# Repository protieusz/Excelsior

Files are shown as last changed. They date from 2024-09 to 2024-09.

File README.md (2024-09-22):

# Excelsior
Excelsior, 34 keys unisplit ortho with staggered pinkies &amp; 25mm trackball, optional RGB strip.

# Description
Excelsior is a heavily modified version of Endzone34 which has been blessed by takashicompany himself for the mod. [Endzone34](https://github.com/takashicompany/endzone34) was originally designed by takashicompany.

A List Of Mods Made To The Original PCB by [takashicompany](https://github.com/takashicompany/endzone34):

-PCB was created from scratch using the outline shape of Endzone34 using EasyEDA.

-A circular hole was created in the middle that can accomodate either a 25mm trackball powered by PMW3360 sensor.

-Base of the trackball holder with lens cut out is integrated into the top case with integrated 5mm switch plate. Top case sits flush with pcb.

-This PCB is capable of hot swap, Kailh.

-Full keyboard case was created to house the PCB.

-MCU area is now hidden and have an extrude of a [Starship logo](https://www.clipartmax.com/middle/m2i8Z5m2d3b1K9m2_star-trek-ship-icon-icon/)

-Excelsior is powered by [RP2040 Zero Raspberry Pi SuperMini Pico](https://www.aliexpress.com/item/1005007292787135.html?spm=a2g0o.order_list.order_list_main.136.6e251802pcq7qH) which you can get from AE and is soldered at the bottom of the pcb flush to the pcb.

-For diodes, I decided to try out the [BAV70](https://www.lcsc.com/product-detail/Switching-Diode_Jiangsu-Changjing-Electronics-Technology-Co-Ltd-BAV70_C68978.html) so that I solder less diodes since this pcb
is not sponsored. I would only need to solder on 17 diodes instead of 34.

-PCB has the option of RGB strip and the power 5v has the proper power level shifter component soldered on. Initially I was gonna do individual 34 RGBs but too much work and I don't use RGBs that often.

-QMK code is borrowed from aki27 bally and modified the matrix to fit my Excelsior. No suppport will be given since I just copy and paste.

-Keycaps I prefer high profile ones, MT3 or SA.

-Use M2 brass hot inserts 3.2mm diameter and 4mm length for the M2 screws to secure the case. I forgot how long is my M2 screws are but they should be greater than 10mm so estimated around 14.6mm. Play around with and buy multiple M2 lenght screws.

# Disclaimer
The trackball user experience might differ depending on the types of 3D printer that you use or if the printers were calibrated properly. It might be a hit and miss. The experience can also be adjust on the QMK side on the CPI settings. No
support will be given since the code was copy pasted from bally by aki27. As for the ball material and sizing plays a big role on the user experience. I personally prefer the BOM ball 25mm compared to the other different materials. Try it out and experiment it. As per usual print and use at your own risk. No support will be given. This design is MIT licensed so that means you can modify and do whatever you want with the design. If you do modify my design, please be kind to give me a shout out. PCB file is converted from EasyEDA so the convertion accuracy might not be good and KiCad DRC will scream but on EasyEDA DRC is fine. As the time of writing, the Excelsior is 100% working with no issues on my end.  Results might differ on your end.  A all in one Fusion file for the case that include the sketches is also included in this GitHub.  Thanks. 

# Full Production Pictures
TBA. Currently Sept 13, 2024, the PCBs are in transit from JLCPCB.
Sept 22, 2024, PCBs have arrived and build was a success!!!






















# Renders
Screenshot 2024-09-13 at 2 24 26 PM
Screenshot 2024-09-13 at 2 24 42 PM





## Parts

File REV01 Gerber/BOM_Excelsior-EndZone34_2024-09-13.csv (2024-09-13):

ID | Name | Designator | Footprint | Quantity | Manufacturer Part | Manufacturer | Supplier | Supplier Part | Price | link
1 | Kailh MX Hotswap | K000,K001,K002,K003,K004,K005,K006,K007,K008,K009,K100,K101,K102,K103,K104,K105,K106,K107,K108,K109,K200,K201,K202,K203,K204,K205,K206,K207,K208,K209,K303,K304,K305,K306 | KAILH MX HOTSWAP | 34 | 4958 | Adafruit Industries LLC | Digi-Key | 1528-4958-ND |  | https://www.digikey.fr/fr/products/detail/adafruit-industries-llc/4958/13997772
2 | NO | 5V,DIN,GND | PIN 1-PIN | 3
3 | SN74LVC1T45QDCKRQ1 | U6 | SC-70-6_L2.0-W1.3-P0.65-LS2.1-BR | 1 | SN74LVC1T45QDCKRQ1 | TI(德州仪器) | LCSC | C139353 | 0.443 | https://lcsc.com/eda_search?q=C139353&%26type=1&ref=editor
4 | RP2040-TINY | U2 | COMM-SMD_23P-P2.54-L23.5-W18.0_RP2040-TINY | 1 | RP2040-Tiny | Waveshare(微雪电子) | LCSC | C7437606 | 5.586 | https://atta.szlcsc.com/upload/public/pdf/source/20230712/B68EE20814230DC1A1AC8A477766A0F3.pdf
5 | PMW3360DM-T2QU | U11 | PMW3360DM-T2QU.PACK | 1 | PMW3360DM-T2QU |  |  |  |  | http://www.pixart.com/upload/PMS0058-PMW3360DM-T2QU-NNDS-R1.30-06042016_20160902201411.pdf
6 | BAV70-C68978 | D000,D002,D004,D006,D008,D100,D102,D104,D106,D108,D200,D202,D204,D206,D208,D303,D305 | SOT-23-3_L3.0-W1.7-P0.95-LS2.9-BR | 17 | BAV70 | CJ(江苏长电/长晶) | LCSC | C68978 | 0.019 | https://item.szlcsc.com/139341.html
7 | 4.7uF | C17,C19,C20 | C0402 | 3 | CL05A475MP5NRNC | SAMSUNG(三星) | LCSC | C23733 | 0.005 | https://lcsc.com/eda_search?q=C23733&%26type=1&ref=editor
8 | 100nF | C18 | C0402 | 1 | CL05B104KB54PNC | SAMSUNG(三星) | LCSC | C307331 | 0.005 | https://lcsc.com/eda_search?q=C307331&%26type=1&ref=editor
9 | 10kΩ | R10,R12,R13 | R0402 | 3 | 0402WGF1002TCE | UNI-ROYAL(厚声) | LCSC | C25744 | 0.001 | https://lcsc.com/eda_search?q=C25744&%26type=1&ref=editor
10 | 39Ω | R11 | R0402 | 1 | 0402WGJ0390TCE | UNI-ROYAL(厚声) | LCSC | C25164 |  | https://lcsc.com/eda_search?q=C25164&%26type=1&ref=editor
11 | 15kΩ | R14 | R0402 | 1 | 0402WGF1502TCE | UNI-ROYAL(厚声) | LCSC | C25756 | 0.001 | https://lcsc.com/eda_search?q=C25756&%26type=1&ref=editor
12 | AP2127K-ADJTRG1 | U10 | SOT-23-5_L3.0-W1.7-P0.95-LS2.8-BR | 1 | AP2127K-ADJTRG1 | DIODES(美台) | LCSC | C96343 | 0.074 | https://lcsc.com/eda_search?q=C96343&%26type=1&ref=editor

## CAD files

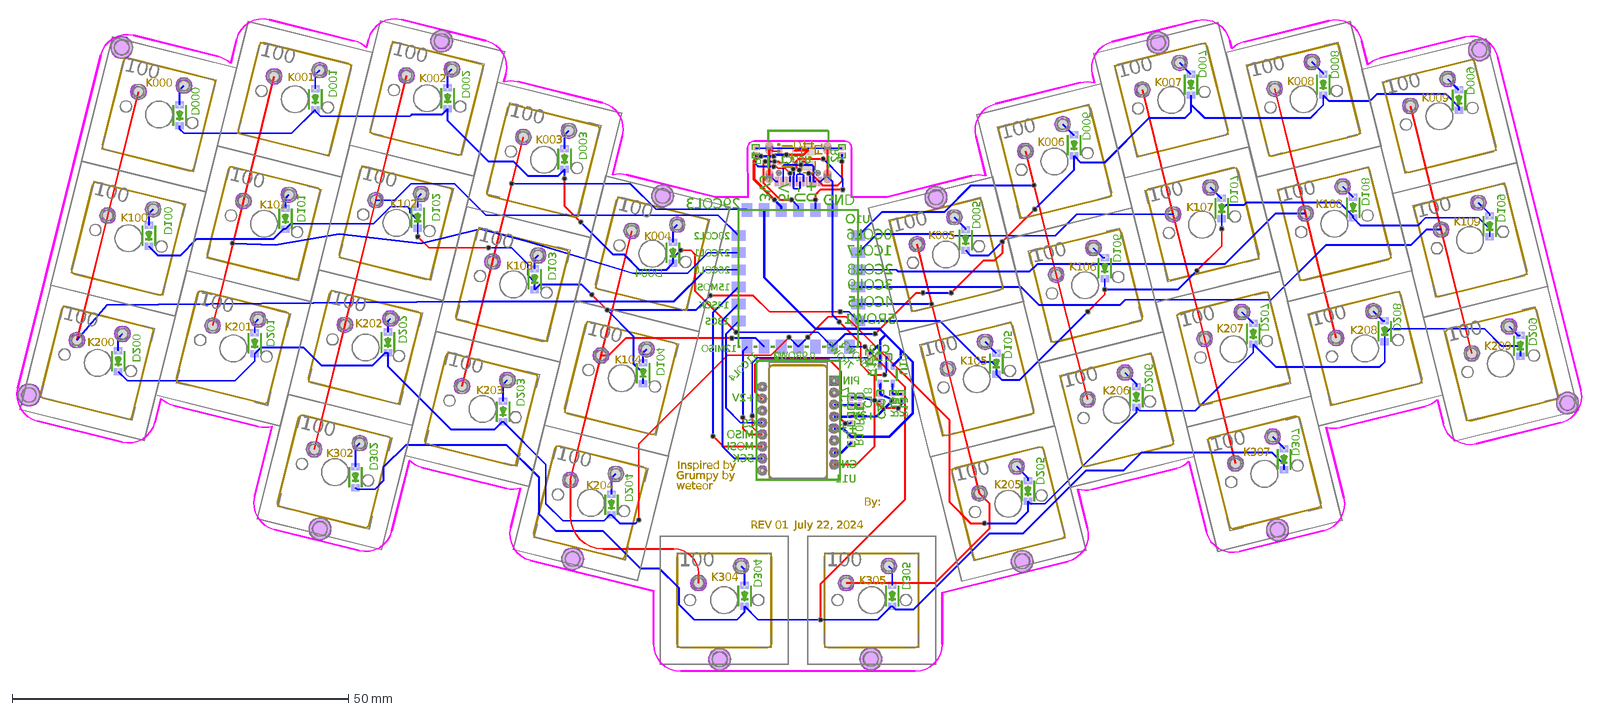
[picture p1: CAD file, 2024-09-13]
PCB_Angel_2024-09-05.dxf
By:
REV 01
July 22, 2024
Inspired by
Grumpy by
weteor
PIN 1
+2V
+3V3
GND
SCK
MOSI
MISO
CS
D000
D001
D002
D003
D004
D005
D006
D007
D008
D009
D100
D101
D102
D103
D104
D105
D106
D107
D108
D109
D200
D201
D202
D203
D204
D205
D206
D207
D208
D209
D302
D304
D305
D307
C17
C18
C19
C20
R1
R2
R10
R11
R12
R13
R14
U1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

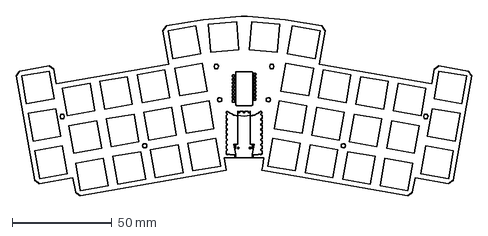
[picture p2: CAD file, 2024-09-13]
pcbtemplate/Excelsior PCB Template.dxf
227.9 x 89.8 mm

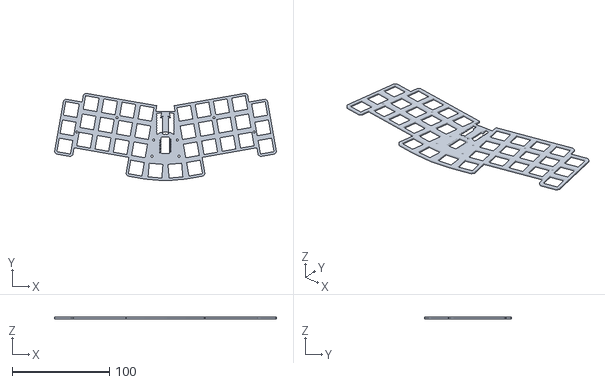
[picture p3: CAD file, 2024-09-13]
STLs/Excelsior PCB.stl
227.9 x 89.8 x 1.60

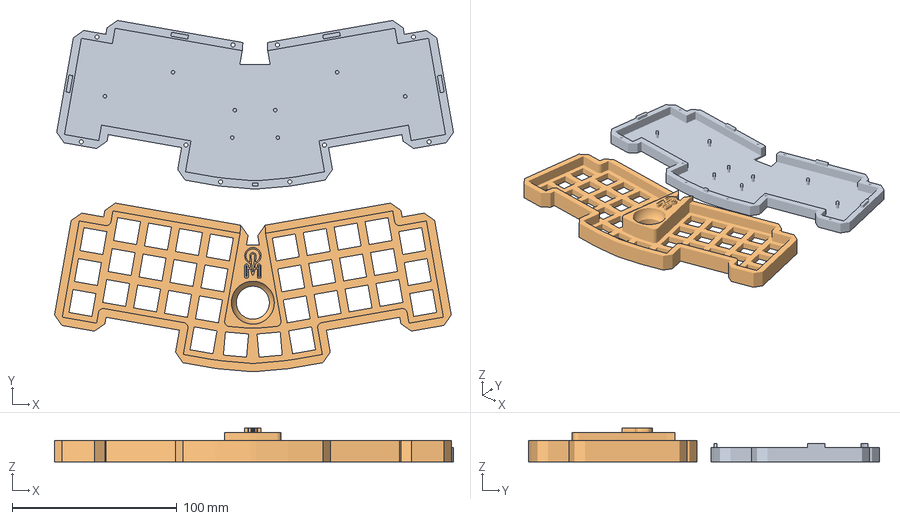
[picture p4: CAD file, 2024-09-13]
STLs/RPL/UMS7_ExcelsiorAll.3mf
241.9 x 212.9 x 20.4 mm
Excelsior Bottom.stl
Excelsior Top.stl

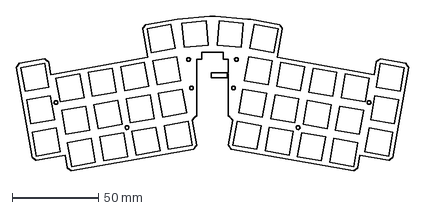
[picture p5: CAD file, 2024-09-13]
Template/Excelsior EndZone34 template.dxf
227.9 x 89.8 mm

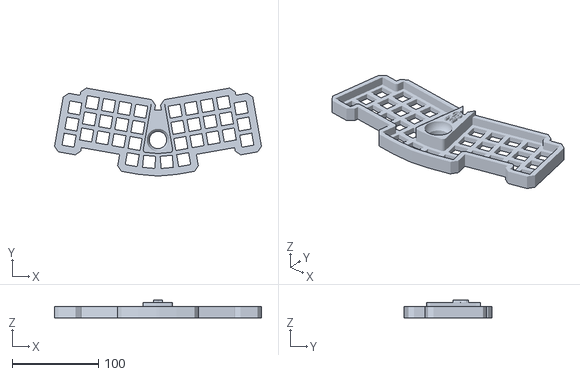
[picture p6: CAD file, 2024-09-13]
STLs/Excelsior Top.stl
240.6 x 102.1 x 20.4

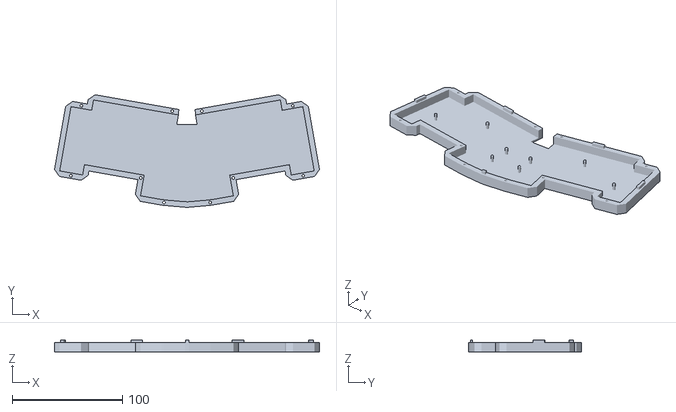
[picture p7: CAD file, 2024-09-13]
STLs/Excelsior Bottom.stl
240.6 x 102.1 x 11.1

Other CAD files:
pcbtemplate/Excelsior PCB.step

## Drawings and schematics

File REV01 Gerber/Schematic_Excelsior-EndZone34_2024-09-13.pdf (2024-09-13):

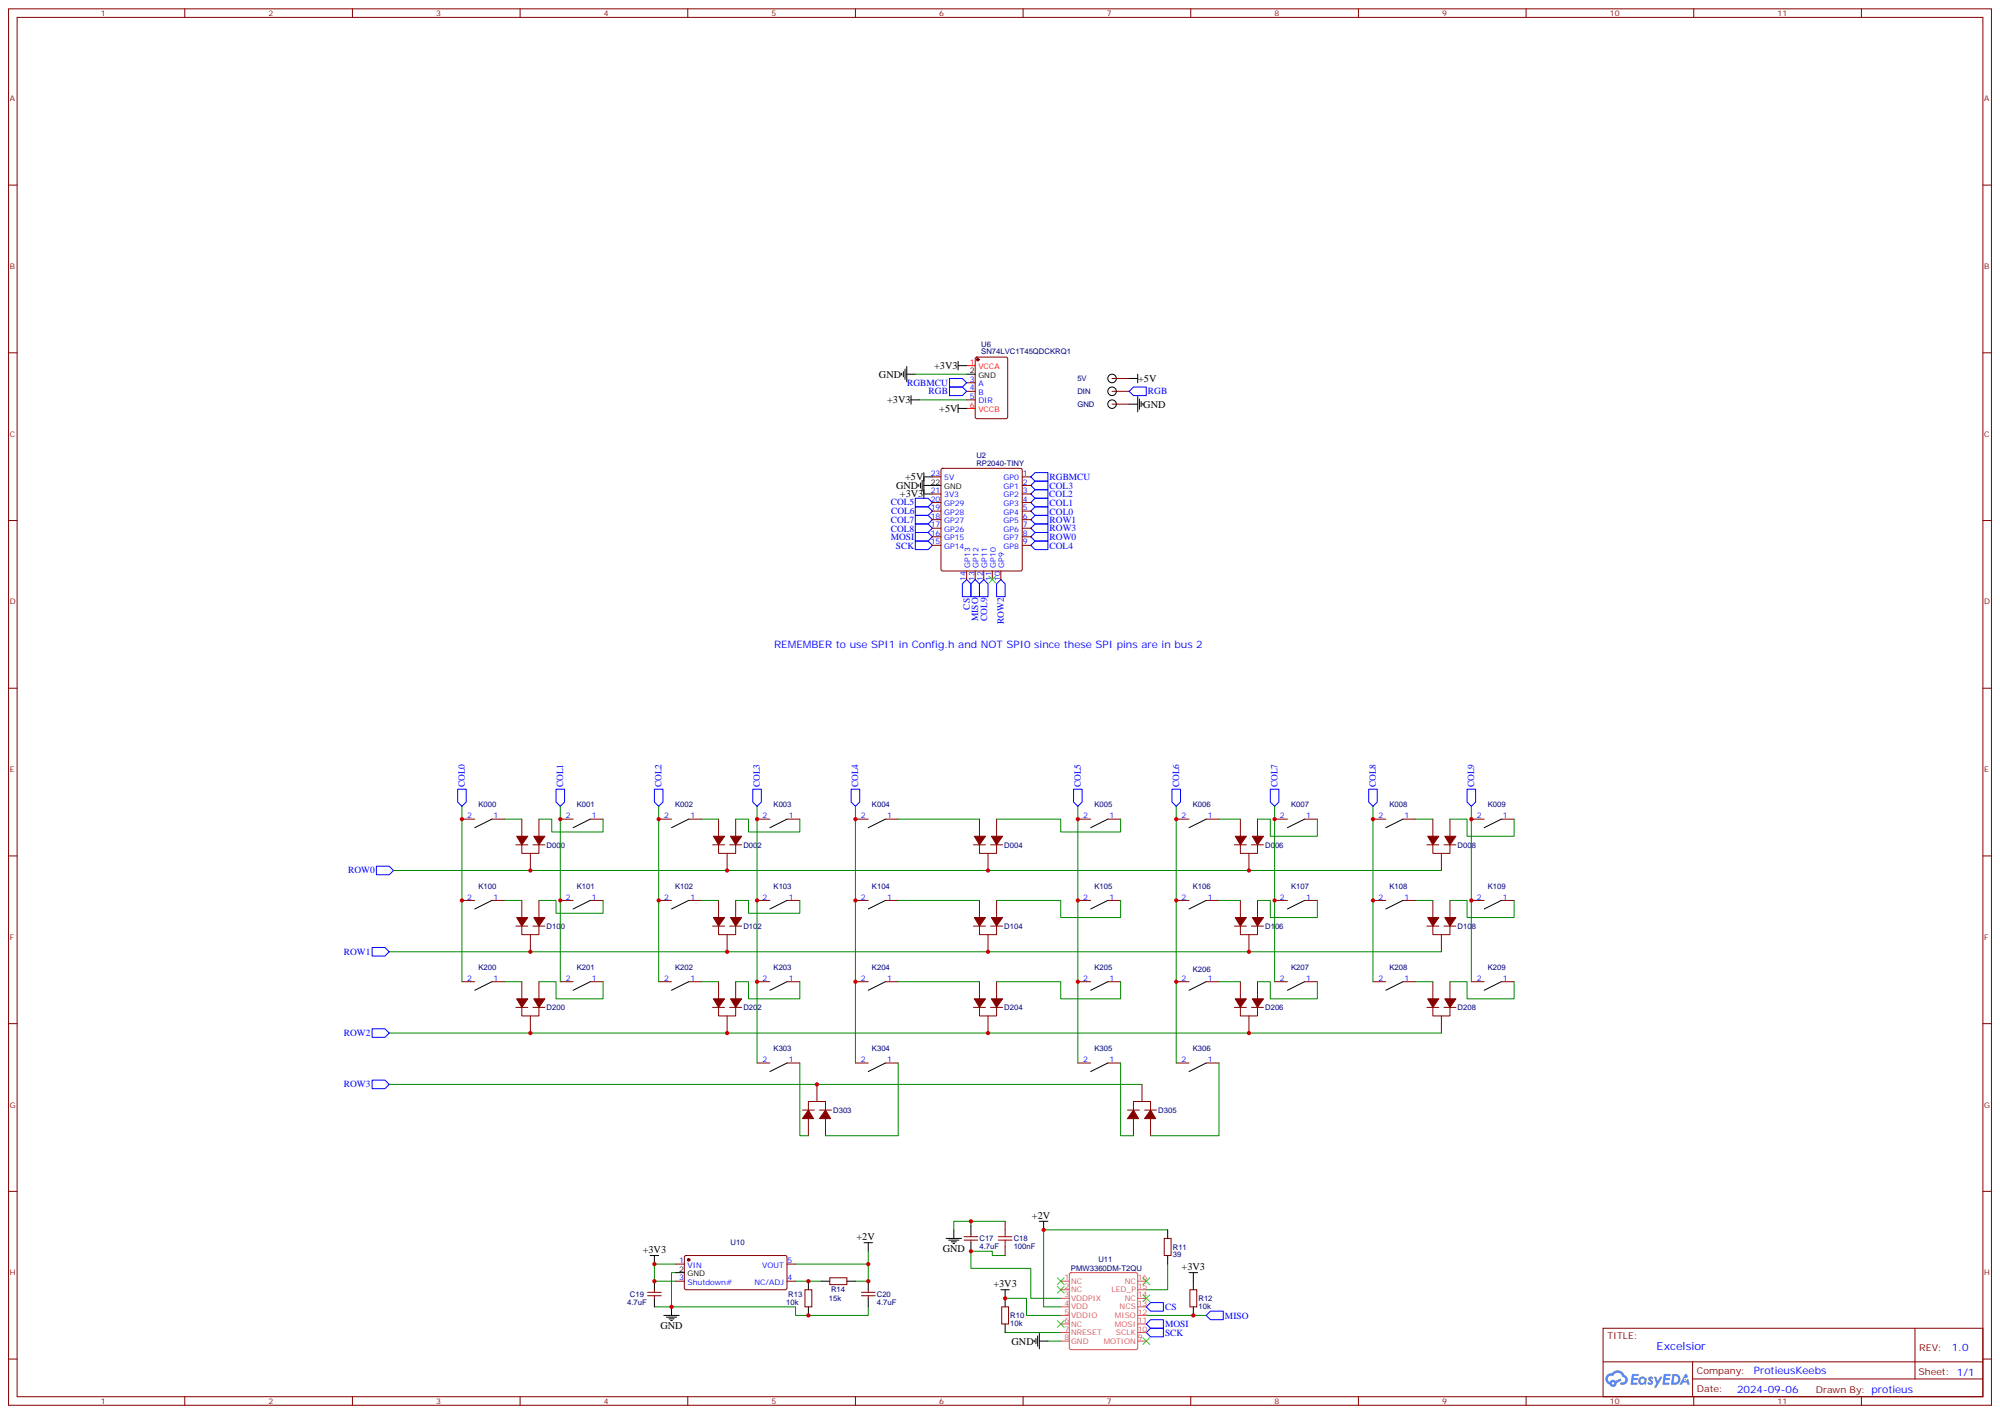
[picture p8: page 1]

REMEMBER to use SPI1 in Config.h and NOT SPI0 since these SPI pins are in bus 2

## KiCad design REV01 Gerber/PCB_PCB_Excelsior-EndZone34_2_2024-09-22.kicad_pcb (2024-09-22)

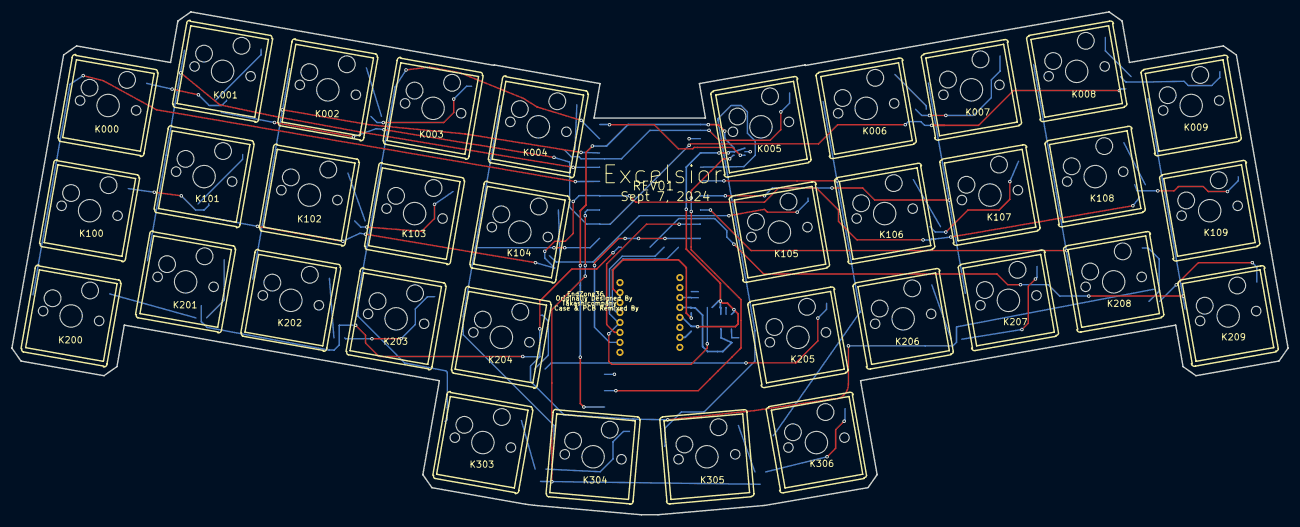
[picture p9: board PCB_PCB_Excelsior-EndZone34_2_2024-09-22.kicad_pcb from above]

Board: 2 copper layers, 227.9 x 89.8 mm, 67 parts (0 on the bottom side), 62 nets.

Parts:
5V: NO; PIN 1-PIN
C17, C19, C20: 4.7uF; C0402
C18: 100nF; C0402
D000, D002, D004, D006, D008, D100, D102, D104, D106, D108, D200, D202, D204, D206, D208, D303, D305: BAV70-C68978; SOT-23-3_L3.0-W1.7-P0.95-LS2.9-BR
DIN: NO; PIN 1-PIN
GND: NO; PIN 1-PIN
K000, K001, K002, K003, K004, K005, K006, K007, K008, K009, K100, K101, K102, K103, K104, K105, K106, K107, K108, K109, K200, K201, K202, K203, K204, K205, K206, K207, K208, K209, K303, K304, K305, K306: Kailh MX Hotswap; KAILH MX HOTSWAP
R10, R12, R13: 10kΩ; R0402
R11: 39Ω; R0402
R14: 15kΩ; R0402
U2: RP2040-TINY; COMM-SMD_23P-P2.54-L23.5-W18.0_RP2040-TINY
U6: SN74LVC1T45QDCKRQ1; SC-70-6_L2.0-W1.3-P0.65-LS2.1-BR
U10: AP2127K-ADJTRG1; SOT-23-5_L3.0-W1.7-P0.95-LS2.8-BR
U11: PMW3360DM-T2QU; PMW3360DM-T2QU.PACK

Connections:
+2V: C20.2, R11.2, R14.2, U10.5, U11.4
+3V3: C19.2, R10.2, R12.2, U2.21, U6.1, U6.5, U10.1, U10.3, U11.5
+5V: 5V.1, U2.23, U6.6
C18_1: C17.1, C18.1, U11.3
COL0: K000.2, K100.2, K200.2, U2.5
COL1: K001.2, K101.2, K201.2, U2.4
COL2: K002.2, K102.2, K202.2, U2.3
COL3: K003.2, K103.2, K203.2, K303.2, U2.2
COL4: K004.2, K104.2, K204.2, K304.2, U2.9
COL5: K005.2, K105.2, K205.2, K305.2, U2.20
COL6: K006.2, K106.2, K206.2, K306.2, U2.19
COL7: K007.2, K107.2, K207.2, U2.18
COL8: K008.2, K108.2, K208.2, U2.17
COL9: K009.2, K109.2, K209.2, U2.12
CS: U2.14, U11.13
GND: C17.2, C18.2, C19.1, C20.1, GND.1, R13.1, U2.22, U6.2, U10.2, U11.8
K000_1: D000.2, K000.1
K001_1: D000.1, K001.1
K002_1: D002.2, K002.1
K003_1: D002.1, K003.1
K004_1: D004.2, K004.1
K005_1: D004.1, K005.1
K006_1: D006.2, K006.1
K007_1: D006.1, K007.1
K008_1: D008.2, K008.1
K009_1: D008.1, K009.1
K100_1: D100.2, K100.1
K101_1: D100.1, K101.1
K102_1: D102.2, K102.1
K103_1: D102.1, K103.1
K104_1: D104.2, K104.1
K105_1: D104.1, K105.1
K106_1: D106.2, K106.1
K107_1: D106.1, K107.1
K108_1: D108.2, K108.1
K109_1: D108.1, K109.1
K200_1: D200.2, K200.1
K201_1: D200.1, K201.1
K202_1: D202.2, K202.1
K203_1: D202.1, K203.1
K204_1: D204.2, K204.1
K205_1: D204.1, K205.1
K206_1: D206.2, K206.1
K207_1: D206.1, K207.1
K208_1: D208.2, K208.1
K209_1: D208.1, K209.1
K303_1: D303.1, K303.1
K304_1: D303.2, K304.1
K305_1: D305.1, K305.1
K306_1: D305.2, K306.1
MISO: R12.1, U2.13, U11.12
MOSI: U2.16, U11.11
R10_1: R10.1, U11.7
R11_1: R11.1, U11.15
R14_1: R13.2, R14.1, U10.4
RGB: DIN.1, U6.4
RGBMCU: U2.1, U6.3
ROW0: D000.3, D002.3, D004.3, D006.3, D008.3, U2.8
ROW1: D100.3, D102.3, D104.3, D106.3, D108.3, U2.6
ROW2: D200.3, D202.3, D204.3, D206.3, D208.3, U2.10
ROW3: D303.3, D305.3, U2.7
SCK: U2.15, U11.10

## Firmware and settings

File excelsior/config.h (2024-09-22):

// Copyright 2024 ProtieusKeebs
// SPDX-License-Identifier: GPL-2.0-or-later

#pragma once

//#define VIAL_KEYBOARD_UID {0xC4, 0x18, 0xCC, 0x6D, 0x1C, 0x16, 0x5B, 0x8D}
//#define VIAL_UNLOCK_COMBO_ROWS {0, 0}
//#define VIAL_UNLOCK_COMBO_COLS {1, 11}

/* VIA */
//#define DYNAMIC_KEYMAP_LAYER_COUNT 8


/* key matrix size */
//#define MATRIX_COLS 13
//#define MATRIX_ROWS 4


/* tapping term */
// #define TAPPING_FORCE_HOLD
//#define TAPPING_TERM 200
// #define IGNORE_MOD_TAP_INTERRUPT

#define RP2040_BOOTLOADER_DOUBLE_TAP_RESET // Activates the double-tap behavior
#define RP2040_BOOTLOADER_DOUBLE_TAP_RESET_TIMEOUT 200U // Timeout window in ms in which the double tap can occur.

#ifdef COMBO_ENABLE
#    define COMBO_COUNT 4
#    define COMBO_TERM 150
#endif

/* Encoder */
//#define ENCODERS_PAD_A { GP11 }
//#define ENCODERS_PAD_B { GP12 }
//#define ENCODER_RESOLUTION 4

/* Matrix*/
//#define MATRIX_COL_PINS { GP25, GP24, GP23, GP22, GP21, GP26, GP27, GP20, GP19, GP18, GP17, GP16, GP13 }
//#define MATRIX_ROW_PINS { GP28, GP10, GP14, GP15 }

/* COL2ROW, ROW2COL */
//#define DIODE_DIRECTION COL2ROW


/* Set 0 if debouncing isn't needed */
//#define DEBOUNCE 5


/* Mechanical locking support. Use KC_LCAP, KC_LNUM or KC_LSCR instead in keymap (Very Important for Scroll Lock!!!) */
#undef LOCKING_SUPPORT_ENABLE
/* Locking resynchronize hack */
#undef LOCKING_RESYNC_ENABLE

/* RGB LED */
//#define WS2812_PIO_USE_PIO1
#define WS2812_DI_PIN GP0

#ifdef RGBLIGHT_ENABLE
    #define RGBLIGHT_LED_COUNT 10
    #define RGBLIGHT_LIMIT_VAL 80
    #define RGBLIGHT_HUE_STEP 10
    #define RGBLIGHT_SAT_STEP 17
    #define RGBLIGHT_VAL_STEP 17

    #define RGBLIGHT_EFFECT_BREATHING
    #define RGBLIGHT_EFFECT_RAINBOW_MOOD
    #define RGBLIGHT_EFFECT_RAINBOW_SWIRL
    #define RGBLIGHT_EFFECT_SNAKE
    #define RGBLIGHT_EFFECT_KNIGHT
    #define RGBLIGHT_EFFECT_CHRISTMAS
    #define RGBLIGHT_EFFECT_STATIC_GRADIENT
    #define RGBLIGHT_EFFECT_TWINKLE
    #define RGBLIGHT_EFFECT_ALTERNATING
#endif


/* Trackball */

#ifdef POINTING_DEVICE_ENABLE

//#    undef RP_SPI_USE_SPI0
//#    define RP_SPI_USE_SPI0 TRUE
//#    undef RP_SPI_USE_SPI1
//#    define RP_SPI_USE_SPI1 FALSE
#    define SPI_DRIVER SPID1

//#    define SPI_SCK_PIN GP22 //6
//#    define SPI_MISO_PIN GP24 //4
//#    define SPI_MOSI_PIN GP23 //7
#    define SPI_SCK_PIN GP14
#    define SPI_MISO_PIN GP12
#    define SPI_MOSI_PIN GP15

#endif


#ifndef PMW33XX_CS_PIN
#    define PMW33XX_CS_PIN GP13
#endif
#define POINTING_DEVICE_INVERT_X
#define POINTING_DEVICE_INVERT_Y
//#define ROTATIONAL_TRANSFORM_ANGLE 90
#define POINTING_DEVICE_ROTATION_180
